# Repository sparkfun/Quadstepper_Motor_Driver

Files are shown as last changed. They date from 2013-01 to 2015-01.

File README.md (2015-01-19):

SparkFun QuadStepper Motor Driver
=================================

SparkFun Quadstepper Motor Driver
[*SparkFun Quadstepper Motor Driver (ROB-10507)*](https://www.sparkfun.com/products/10507)

The Quadstepper motor driver board allows you to control up to 4 bipolar stepper motors simultaneously using logic level IO pins. 
Each motor driver has an output drive capacity of 35V and 1Amps. The board is capable of driving motors in full, half, quarter, eight, 
and sixteenth-step modes. The logic levels are selectable between 3.3V and 5V by way of a jumper. The bus header allows you to control 
all four motors with only 6 IO pins by controlling the enable (EN pins) for each motor, although each motor will be activated alone, not simultaneously. 
Be sure to close all of the ‘Bus Enable’ jumpers on the back of the board in order to use the Bus header.

Repository Contents
-------------------
* **/Hardware** - All Eagle design files (.brd, .sch, .STL)
* **/Libraries** - All Arduino libraries and board examples

License Information
-------------------
The hardware is released under [Creative Commons ShareAlike 4.0 International](https://creativecommons.org/licenses/by-sa/4.0/).
The code is beerware; if you see me (or any other SparkFun employee) at the local, and you've found our code helpful, please buy us a round!

Distributed as-is; no warranty is given.

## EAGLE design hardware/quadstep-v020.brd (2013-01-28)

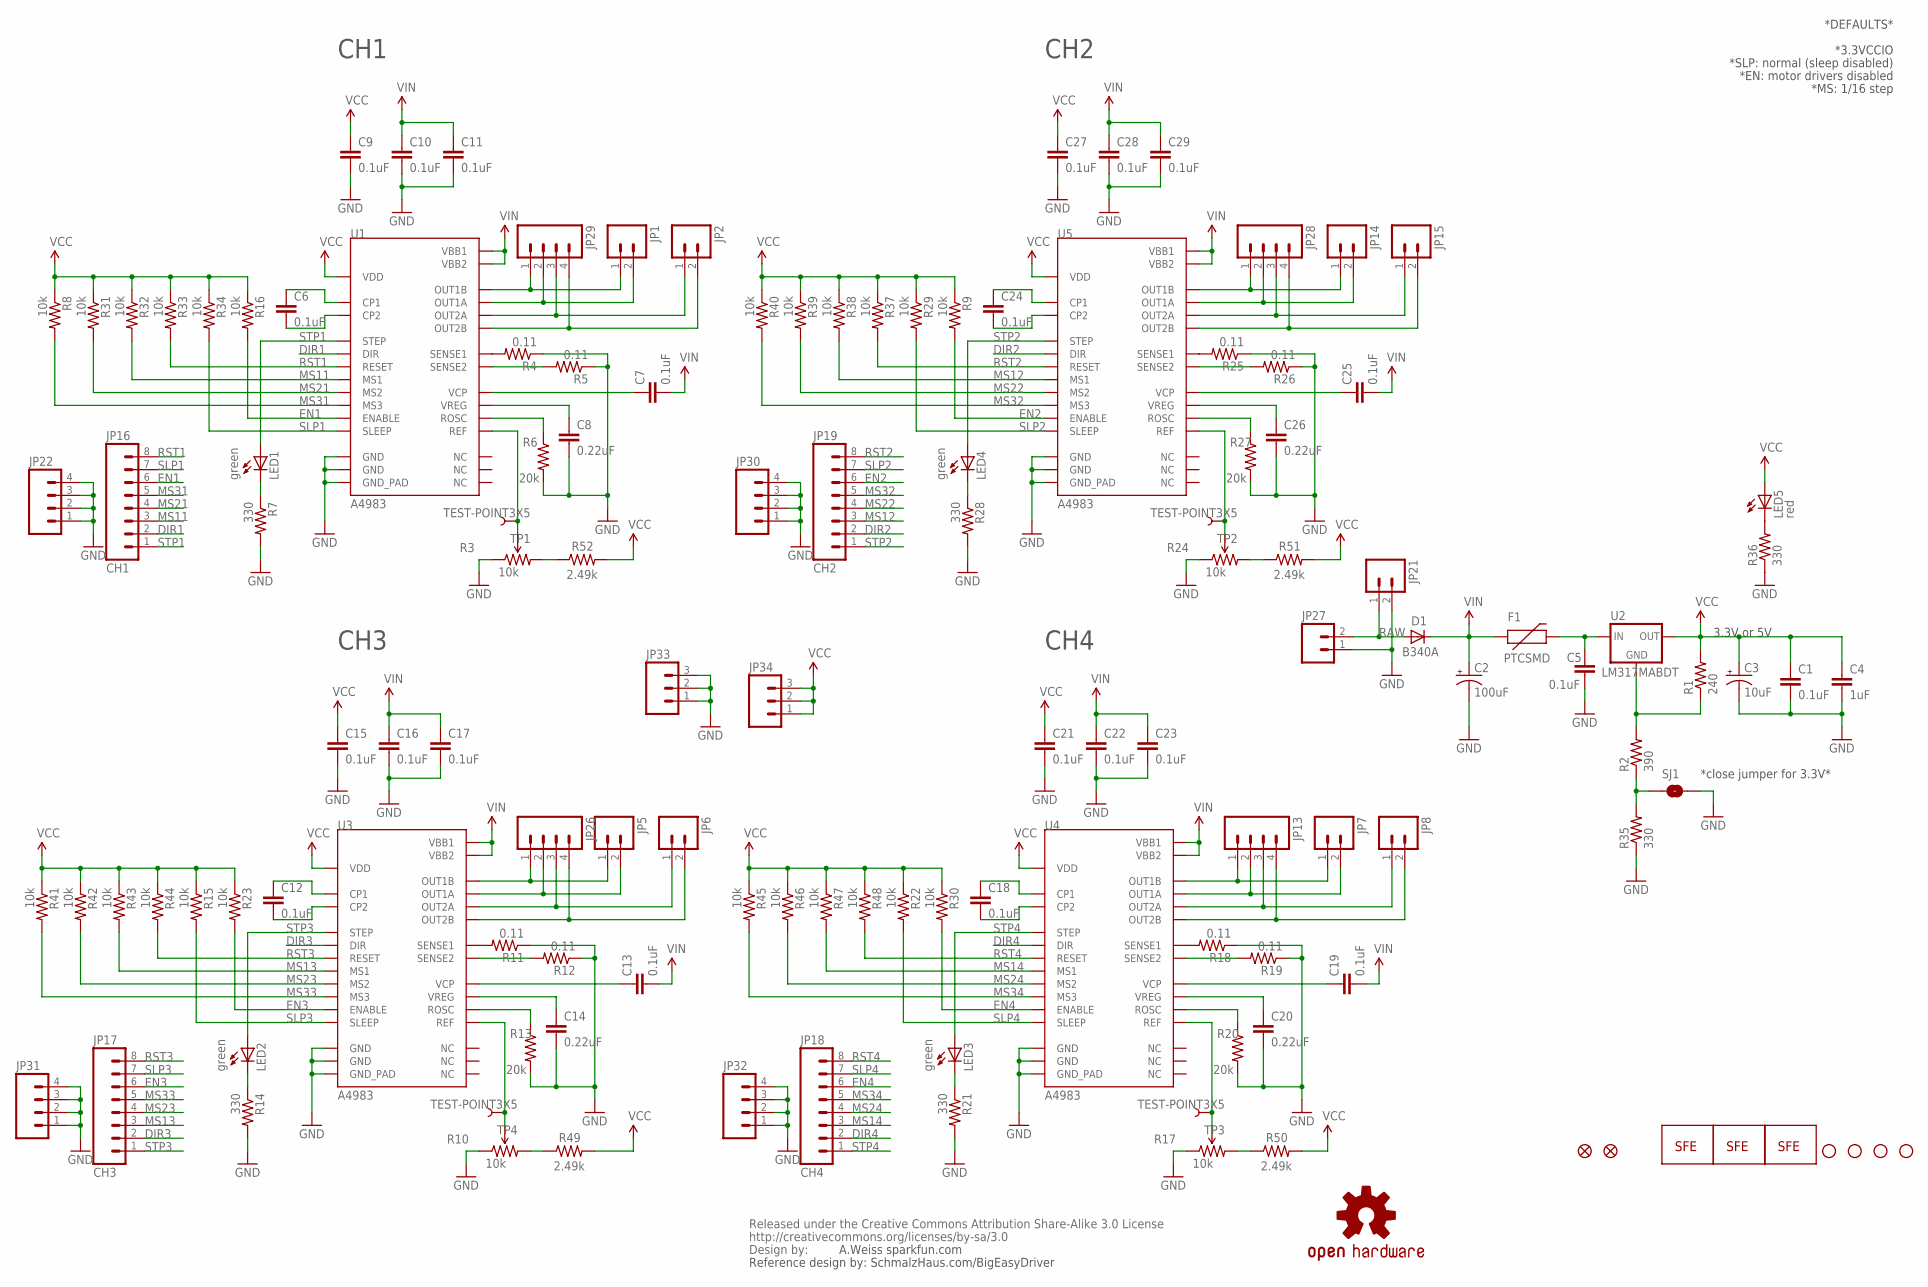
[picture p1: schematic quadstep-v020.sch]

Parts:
C1, C5, C6, C7, C9, C10, C11, C12, C13, C15, C16, C17, C18, C19, C21, C22, C23, C24, C25, C27, C28, C29: 0.1uF; 0402-CAP
C2: 100uF; PANASONIC_G
C3: 10uF; EIA3216
C4: 1uF; 0805
C8, C14, C20, C26: 0.22uF; 0402-CAP
CC_TEXT1: CREATIVE_COMMONS
D1: B340A; SMA-DIODE
F1: PTCSMD; PTC-1206
JP1, JP2, JP5, JP6, JP7, JP8, JP14, JP15: M023.5MM_LOCK; SCREWTERMINAL-3.5MM-2_LOCK
JP9, JP10, JP11, JP12: STAND-OFF
JP13, JP22, JP26, JP28, JP29, JP30, JP31, JP32: M04PTH; 1X04
JP16: CH1; 1X08
JP17: CH3; 1X08
JP18: CH4; 1X08
JP19: CH2; 1X08
JP20: LOGO-SFENEW; SFE-NEW-WEBLOGO
JP21: M025MM; SCREWTERMINAL-5MM-2
JP23: LOGO-SFESK; SFE-LOGO-FLAME
JP24, JP25: FIDUCIAL1X2; FIDUCIAL-1X2
JP27: M02PTH; 1X02
JP33, JP34: M03PTH; 1X03
LED1, LED2, LED3, LED4: green; LED-0603
LED5: red; LED-0603
LOGO1: LOGO-SFENW2; SFE-NEW-WEB
R1: 240; 0402-RES
R2: 390; 0402-RES
R3, R10, R17, R24: 10k; TRIMPOT-3MM
R4, R5, R11, R12, R18, R19, R25, R26: 0.11; R2010
R6, R13, R20, R27: 20k; 0402-RES
R7, R14, R21, R28, R35, R36: 330; 0402-RES
R8, R9, R15, R16, R22, R23, R29, R30, R31, R32, R33, R34, R37, R38, R39, R40, R41, R42, R43, R44, R45, R46, R47, R48: 10k; 0402-RES
R49, R50, R51, R52: 2.49k; 0402-RES
SJ1: SOLDERJUMPERNO; SJ_2S-NO
TP1, TP2, TP3, TP4: TEST-POINT3X5; PAD.03X.05
U1, U3, U4, U5: A4983; QFN-28-5MM
U2: LM317MABDT; DPAK
U$1: OSHW-LOGOS; OSHW-LOGO-S

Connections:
DIR1: JP16.2, U1.P$19 (DIR)
DIR2: JP19.2, U5.P$19 (DIR)
DIR3: JP17.2, U3.P$19 (DIR)
DIR4: JP18.2, U4.P$19 (DIR)
EN1: JP16.6, R16.2, U1.P$2 (ENABLE)
EN2: JP19.6, R9.2, U5.P$2 (ENABLE)
EN3: JP17.6, R23.2, U3.P$2 (ENABLE)
EN4: JP18.6, R30.2, U4.P$2 (ENABLE)
GND: C1.2, C2.-, C3.C (-), C4.2, C5.2, C8.2, C9.2, C10.2, C11.2, C14.2, C15.2, C16.2, C17.2, C20.2, C21.2, C22.2, C23.2, C26.2, C27.2, C28.2, C29.2, JP21.2, JP22.1, JP22.2, JP22.3, JP22.4, JP27.1, JP30.1, JP30.2, JP30.3, JP30.4, JP31.1, JP31.2, JP31.3, JP31.4, JP32.1, JP32.2, JP32.3, JP32.4, JP33.1, JP33.2, JP33.3, R3.1 (CCW), R4.1, R5.1, R6.2, R7.2, R10.1 (CCW), R11.1, R12.1, R13.2, R14.2, R17.1 (CCW), R18.1, R19.1, R20.2, R21.2, R24.1 (CCW), R25.1, R26.1, R27.2, R28.2, R35.1, R36.1, SJ1.2, U1.P$3 (GND), U1.P$18 (GND), U1.P$29 (GND_PAD), U3.P$3 (GND), U3.P$18 (GND), U3.P$29 (GND_PAD), U4.P$3 (GND), U4.P$18 (GND), U4.P$29 (GND_PAD), U5.P$3 (GND), U5.P$18 (GND), U5.P$29 (GND_PAD)
MS11: JP16.3, R32.2, U1.P$9 (MS1)
MS12: JP19.3, R38.2, U5.P$9 (MS1)
MS13: JP17.3, R43.2, U3.P$9 (MS1)
MS14: JP18.3, R47.2, U4.P$9 (MS1)
MS21: JP16.4, R31.2, U1.P$10 (MS2)
MS22: JP19.4, R39.2, U5.P$10 (MS2)
MS23: JP17.4, R42.2, U3.P$10 (MS2)
MS24: JP18.4, R46.2, U4.P$10 (MS2)
MS31: JP16.5, R8.2, U1.P$11 (MS3)
MS32: JP19.5, R40.2, U5.P$11 (MS3)
MS33: JP17.5, R41.2, U3.P$11 (MS3)
MS34: JP18.5, R45.2, U4.P$11 (MS3)
unnamed: R1.1, R2.2, U2.1 (GND)
unnamed: JP7.1, JP13.1, U4.P$21 (OUT1B)
unnamed: JP1.2, JP29.2, U1.P$24 (OUT1A)
unnamed: C5.1, F1.2, U2.3 (IN)
unnamed: JP5.1, JP26.1, U3.P$21 (OUT1B)
unnamed: JP2.1, JP29.3, U1.P$26 (OUT2A)
unnamed: JP2.2, JP29.4, U1.P$1 (OUT2B)
unnamed: R4.2, U1.P$23 (SENSE1)
unnamed: R5.2, U1.P$27 (SENSE2)
unnamed: C7.1, U1.P$6 (VCP)
unnamed: C8.1, U1.P$8 (VREG)
unnamed: R6.1, U1.P$13 (ROSC)
unnamed: C6.1, U1.P$4 (CP1)
unnamed: R3.2 (WIPER), TP1.P$1, U1.P$17 (REF)
unnamed: C6.2, U1.P$5 (CP2)
unnamed: R11.2, U3.P$23 (SENSE1)
unnamed: LED1.C, R7.1
unnamed: R12.2, U3.P$27 (SENSE2)
unnamed: C13.1, U3.P$6 (VCP)
unnamed: C14.1, U3.P$8 (VREG)
unnamed: R13.1, U3.P$13 (ROSC)
unnamed: R10.2 (WIPER), TP4.P$1, U3.P$17 (REF)
unnamed: C12.1, U3.P$4 (CP1)
unnamed: R2.1, R35.2, SJ1.1
unnamed: C12.2, U3.P$5 (CP2)
unnamed: LED2.C, R14.1
unnamed: LED5.C, R36.2
unnamed: R10.3 (CW), R49.1
unnamed: JP5.2, JP26.2, U3.P$24 (OUT1A)
unnamed: JP6.1, JP26.3, U3.P$26 (OUT2A)
unnamed: JP6.2, JP26.4, U3.P$1 (OUT2B)
unnamed: R18.2, U4.P$23 (SENSE1)
unnamed: R19.2, U4.P$27 (SENSE2)
unnamed: C19.1, U4.P$6 (VCP)
unnamed: C20.1, U4.P$8 (VREG)
unnamed: R20.1, U4.P$13 (ROSC)
unnamed: R17.2 (WIPER), TP3.P$1, U4.P$17 (REF)
unnamed: C18.1, U4.P$4 (CP1)
unnamed: C18.2, U4.P$5 (CP2)
unnamed: LED3.C, R21.1
unnamed: JP14.1, JP28.1, U5.P$21 (OUT1B)
unnamed: JP7.2, JP13.2, U4.P$24 (OUT1A)
unnamed: JP8.1, JP13.3, U4.P$26 (OUT2A)
unnamed: JP8.2, JP13.4, U4.P$1 (OUT2B)
unnamed: R25.2, U5.P$23 (SENSE1)
unnamed: R26.2, U5.P$27 (SENSE2)
unnamed: C25.1, U5.P$6 (VCP)
unnamed: C26.1, U5.P$8 (VREG)
unnamed: R27.1, U5.P$13 (ROSC)
unnamed: R24.2 (WIPER), TP2.P$1, U5.P$17 (REF)
unnamed: C24.1, U5.P$4 (CP1)
unnamed: C24.2, U5.P$5 (CP2)
unnamed: LED4.C, R28.1
unnamed: JP1.1, JP29.1, U1.P$21 (OUT1B)
unnamed: JP14.2, JP28.2, U5.P$24 (OUT1A)
unnamed: JP15.1, JP28.3, U5.P$26 (OUT2A)
unnamed: JP15.2, JP28.4, U5.P$1 (OUT2B)
unnamed: R17.3 (CW), R50.1
unnamed: R24.3 (CW), R51.1
unnamed: R3.3 (CW), R52.1
RAW: D1.A, JP21.1, JP27.2
RST1: JP16.8, R33.2, U1.P$12 (RESET)
RST2: JP19.8, R37.2, U5.P$12 (RESET)
RST3: JP17.8, R44.2, U3.P$12 (RESET)
RST4: JP18.8, R48.2, U4.P$12 (RESET)
SLP1: JP16.7, R34.2, U1.P$14 (SLEEP)
SLP2: JP19.7, R29.2, U5.P$14 (SLEEP)
SLP3: JP17.7, R15.2, U3.P$14 (SLEEP)
SLP4: JP18.7, R22.2, U4.P$14 (SLEEP)
STP1: JP16.1, LED1.A, U1.P$16 (STEP)
STP2: JP19.1, LED4.A, U5.P$16 (STEP)
STP3: JP17.1, LED2.A, U3.P$16 (STEP)
STP4: JP18.1, LED3.A, U4.P$16 (STEP)
VCC: C1.1, C3.A (+), C4.1, C9.1, C15.1, C21.1, C27.1, JP34.1, JP34.2, JP34.3, LED5.A, R1.2, R8.1, R9.1, R15.1, R16.1, R22.1, R23.1, R29.1, R30.1, R31.1, R32.1, R33.1, R34.1, R37.1, R38.1, R39.1, R40.1, R41.1, R42.1, R43.1, R44.1, R45.1, R46.1, R47.1, R48.1, R49.2, R50.2, R51.2, R52.2, U1.P$15 (VDD), U2.4 (OUT), U3.P$15 (VDD), U4.P$15 (VDD), U5.P$15 (VDD)
VIN: C2.+, C7.2, C10.1, C11.1, C13.2, C16.1, C17.1, C19.2, C22.1, C23.1, C25.2, C28.1, C29.1, D1.C, F1.1, U1.P$22 (VBB1), U1.P$28 (VBB2), U3.P$22 (VBB1), U3.P$28 (VBB2), U4.P$22 (VBB1), U4.P$28 (VBB2), U5.P$22 (VBB1), U5.P$28 (VBB2)

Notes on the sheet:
CH1
CH2
CH3
CH4
*DEFAULTS*
*MS: 1/16 step
*3.3VCCIO
*close jumper for 3.3V*
*EN: motor drivers disabled
*SLP: normal (sleep disabled)
A.Weiss sparkfun.com
Reference design by: SchmalzHaus.com/BigEasyDriver
3.3V or 5V

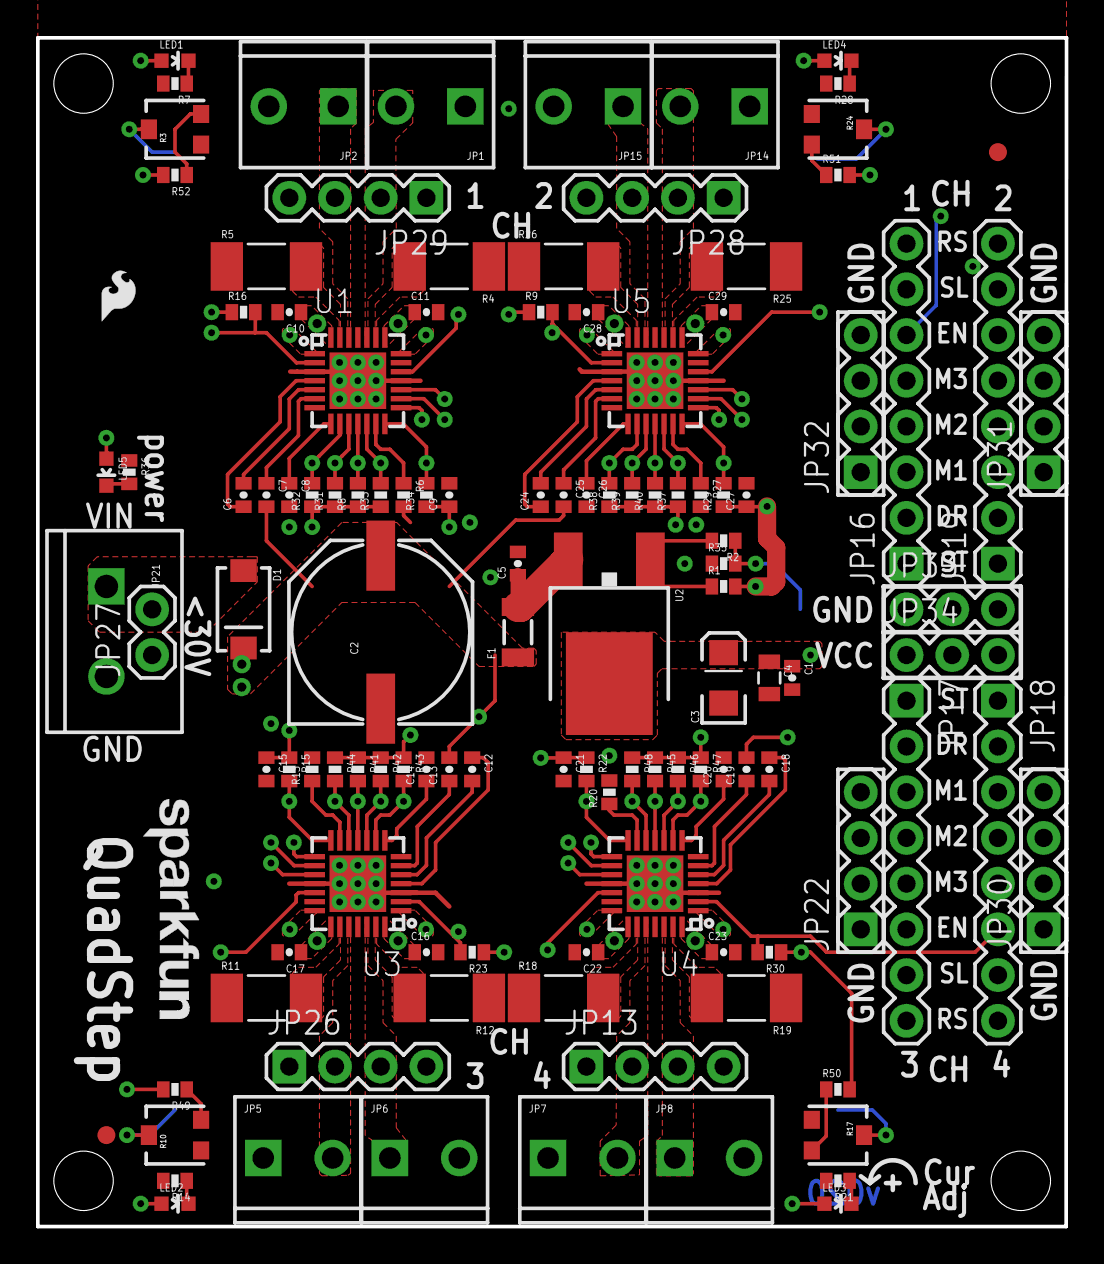
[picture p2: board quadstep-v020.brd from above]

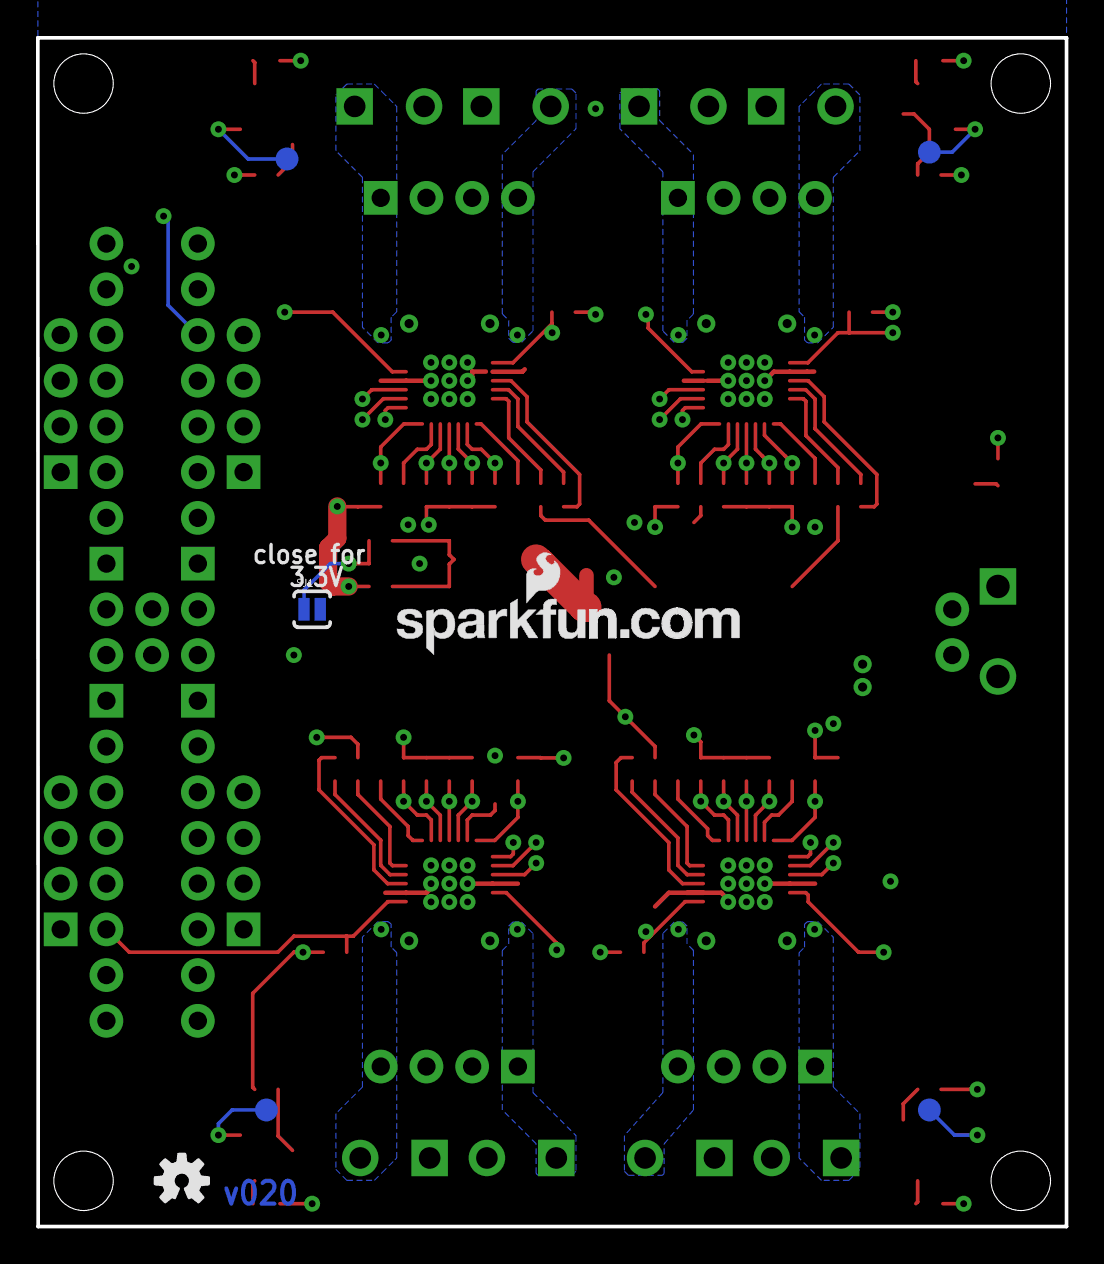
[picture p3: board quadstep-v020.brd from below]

Board: 4 copper layers, 57.1 x 66.0 mm, 133 parts (7 on the bottom side), 96 nets.

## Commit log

2013-02-01 prototype v020
    [quadstep.brd, quadstep.sch]
2013-02-04 v020 proto
    -added standoffs for heatsinks
    -changed A4988 FP
    [quadstep.brd, quadstep.sch]
2015-01-19 Updating README and adding in Arduino libraries
2015-01-19 Updating to current board files
    [SparkFun_quadstep-v11assembly.brd, SparkFun_quadstep-v11assembly.sch, quadstep.brd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]
2015-01-19 Fixing GitHub file directory weirdness
    [SparkFun_quadstep-v11assembly.brd, SparkFun_quadstep-v11assembly.sch]
2015-01-19 Adding back in hardware files
    [SparkFun_quadstep-v11assembly.brd, SparkFun_quadstep-v11assembly.sch]
2015-04-24 Squashed 'Libraries/Arduino/' content from commit 8feeb15
    git-subtree-dir: Libraries/Arduino
    git-subtree-split: 8feeb151bedc8d5ba55fc6744196e73500bd2357
2015-05-07 Squashed 'Libraries/Arduino/' changes from 8feeb15..45fd100
    git-subtree-split: 45fd1007f1f4302c1e057c1e230df1cb51fb9a41
    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

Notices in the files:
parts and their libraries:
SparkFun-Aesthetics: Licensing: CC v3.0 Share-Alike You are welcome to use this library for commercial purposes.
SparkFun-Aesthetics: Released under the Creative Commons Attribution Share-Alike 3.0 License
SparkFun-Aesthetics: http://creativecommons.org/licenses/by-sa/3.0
